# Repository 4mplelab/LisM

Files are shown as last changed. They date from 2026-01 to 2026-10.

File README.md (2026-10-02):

# LisM — 3Dモデル

モジュールを交換できる分割キーボード **LisM** のケース・キーキャップの3Dデータを公開しています。
このリポジトリでは3Dモデルを管理し、製品紹介やビルドガイドはWebサイトで案内しています。

## ドキュメント

- [LisM 製品紹介](https://4mplelab.github.io/LisM/)
- [ビルドガイド](https://4mplelab.github.io/LisM/build_guides/)

## 3Dデータ

データ形式は **STEP** です。

| 種類 | 保存先 |
| --- | --- |
| 本体ケース | [3d-data/case](3d-data/case/) |
| モジュールケース | [3d-data/case/modules](3d-data/case/modules/) |
| トラックボールユニット | [3d-data/case/units](3d-data/case/units/) |
| 旧型ケース | [3d-data/case/old_type](3d-data/case/old_type/) |
| キーキャップ | [3d-data/keycaps](3d-data/keycaps/) |

印刷前に、[ケースの印刷条件・オブジェクト構成](3d-data/case/README.md)や[キーキャップの説明](3d-data/keycaps/README.md)をご確認ください。
本体ケースのファイル名にある `v1.x.x` は、対応するPCBのバージョンを示します。

## ライセンス

データごとにライセンスが異なります。

- ケース： [CC BY-NC-SA 4.0](3d-data/case/LICENSE)
- キーキャップ： [CC BY 4.0](3d-data/keycaps/LICENSE)
- リポジトリルートのライセンス： [MIT](LICENSE)

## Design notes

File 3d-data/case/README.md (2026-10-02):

# ケースデータ



## 推奨印刷条件

各データは以下の条件で最適化されています。  
環境によっては正常に印刷できない可能性があります。

- 本体  
   `Bambu Lab P1S`, `0.4mmノズル`, `Standard品質`  

- その他 (モジュール・トラックボールケース)  
   `Bambu Lab A1 Mini`, `0.2mmノズル`, `Standard品質`

### ボトムケースの印刷方向

**ボトムケースは、底面がビルドプレートに対して垂直になるように立てて印刷してください。**
寝かせて印刷すると、はめ込み時に穴が潰れるため、底面をビルドプレートに置く向きでは印刷しないでください。

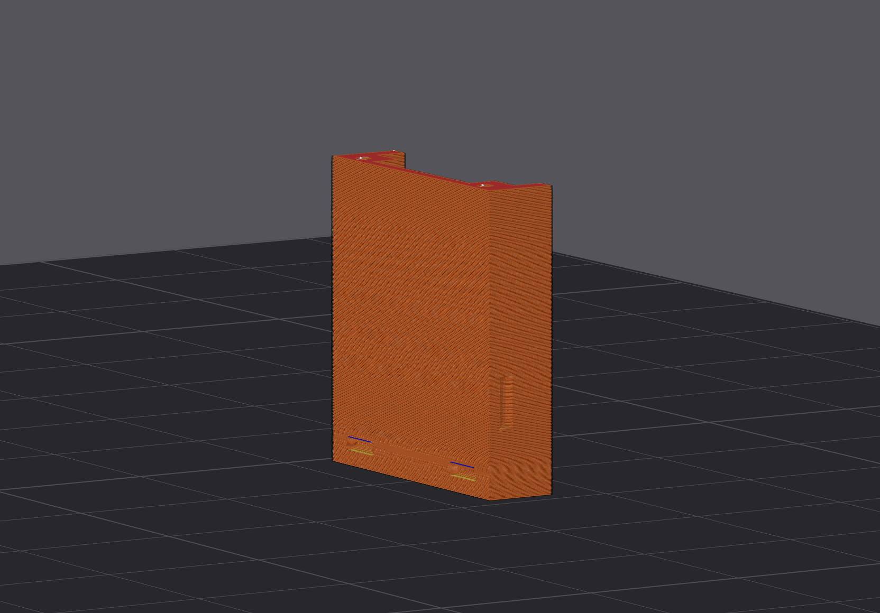
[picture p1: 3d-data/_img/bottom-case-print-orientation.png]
ボトムケースを立てて配置した印刷例


## STEPファイルのオブジェクト構成について

一部のSTEPファイルには、複数のデザインバリエーションが重なった状態で格納されています。(例: 本体ケースの、フラットデザイン・フローティングデザイン・リブ)  
任意の組み合わせ(例: フラットのみ、フローティング+リブ など)で印刷できるよう、CAD上でオブジェクトの表示/非表示を切り替えてご利用ください。

⚠️ 一部のオブジェクトが他のオブジェクトの陰に隠れて見えない場合があります。  
印刷前に、STEPファイル内のオブジェクト構成を必ずご確認ください。

## ファイル名のバージョンについて

`v1.x.x`の表記は、ケースのバージョンではなく**PCBのバージョン**を示しています。  
バージョンがご不明な場合は、PCB基板に印字されていますのでご確認ください。

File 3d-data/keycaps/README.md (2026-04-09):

# キーキャップデータ



## LAK 17mmピッチ用

<a href="../_img/lak17.png">
  
</a>

<a href="../_img/lak17_h.png">
  
</a>

**サイズ:** W 16.2mm × D 16.2mm × H 約6mm

### 確認済みキースイッチ

- Kailh Deep Sea Silent Mini
- Lofree Hades / Void
- Kailh Black Cloud
- Kailh Purple Iris
  
### 印刷

#### 確認済み環境

| 項目 | 値 |
|---|----|
| プリンター | Bambu Lab A1 Mini |
| ノズル | 0.2mm |
| 品質 | Standard |

#### スライス例   
<a href="../_img/lak17_slice.png">
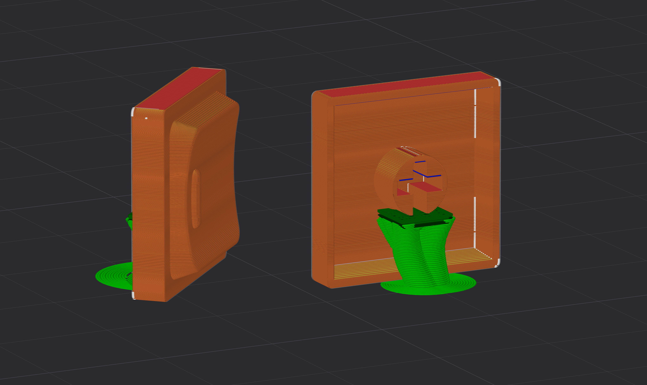
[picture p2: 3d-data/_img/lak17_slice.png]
  
</a>

---

### 注記
このキーキャップは、LAKプロファイルにインスパイアされています。  
形状は異なる寸法で独自に再設計したものであり、Chosfoxのオリジナル設計ファイルは一切使用していません。

> ⚠️ 第三者の知的財産権に関する保証はありません。  
> 商用利用前に、各自で知的財産権の状況を確認してください。

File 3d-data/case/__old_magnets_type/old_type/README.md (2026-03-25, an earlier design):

古いタイプのケースデータです。  
使用されている方もいると思うので互換性のために残しています。

現行はトラボセンサーをトラボケースに引っ掛ける使用ですが、それ以前のデータです。

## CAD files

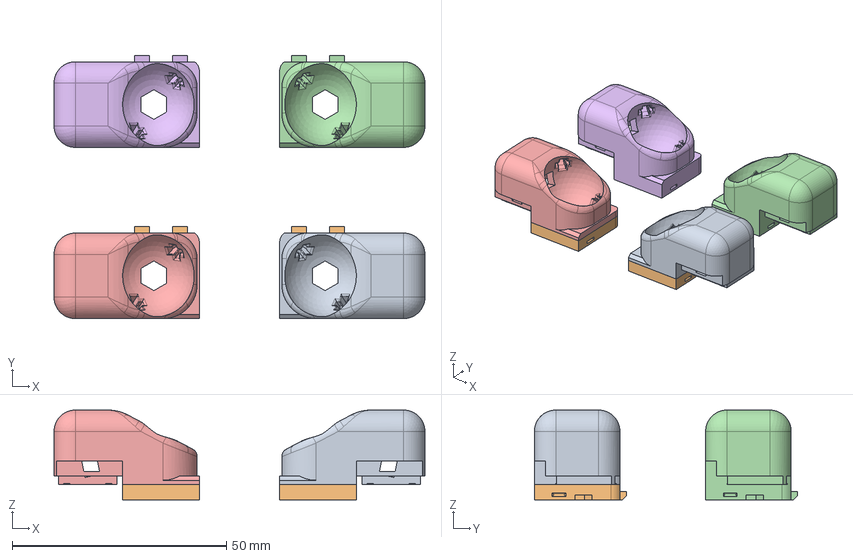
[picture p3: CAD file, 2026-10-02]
3d-data/case/units/TrackBall19mm.step
86.7 x 61.5 x 21.0 mm
19mmCase_Right_Cut
19mmCase_Right
19mmCase_Left_Cut
19mmCase_Left

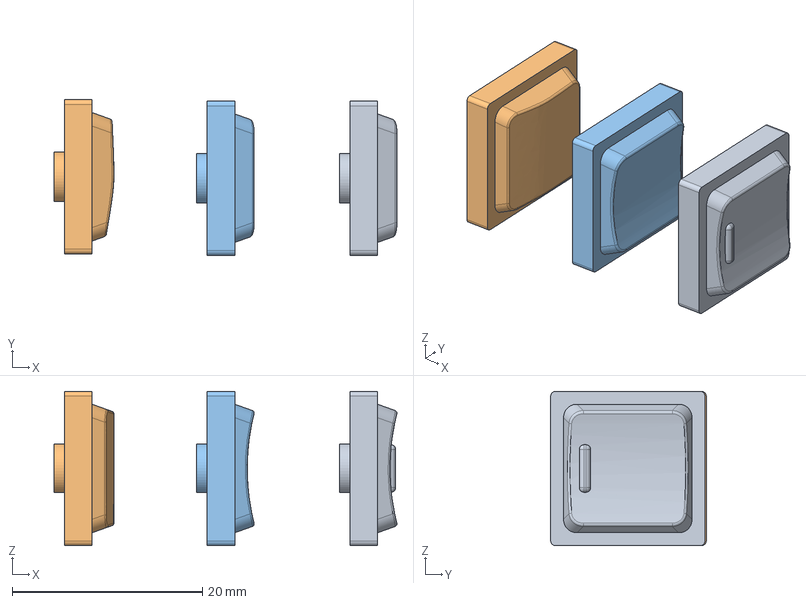
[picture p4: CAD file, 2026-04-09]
3d-data/keycaps/LAK_17mm.step
36.0 x 16.3 x 16.2 mm
Homing
Convex
Normal

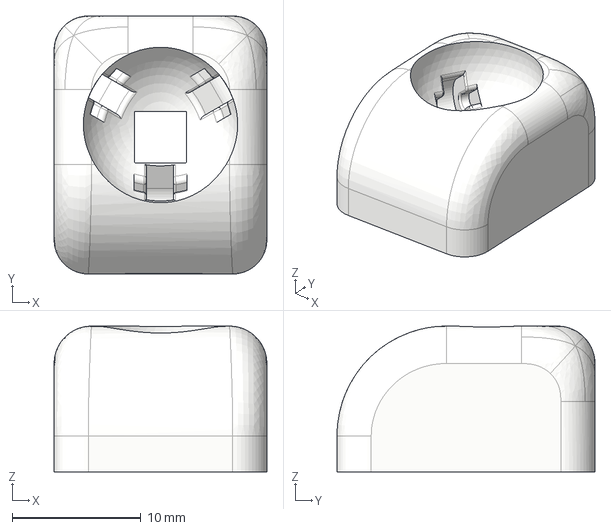
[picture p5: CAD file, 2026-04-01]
3d-data/case/units/TrackBall12mm.step
16.5 x 20.0 x 11.3 mm

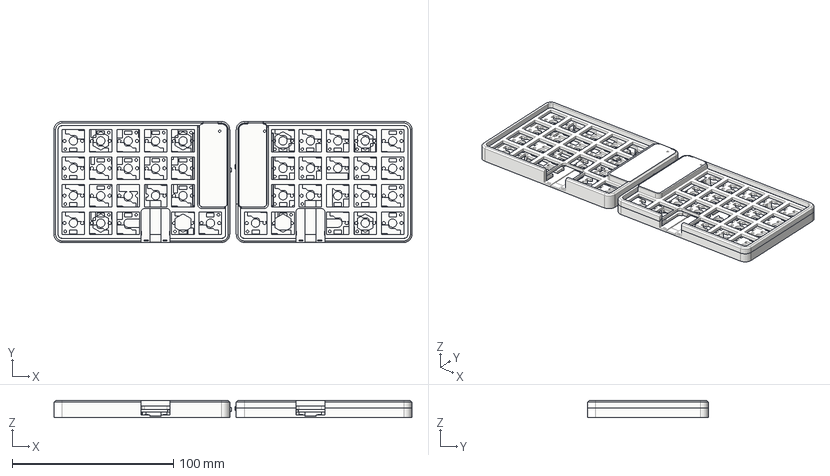
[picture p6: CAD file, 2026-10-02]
3d-data/case/LisM_v1.2.0.step
222.0 x 75.0 x 10.7 mm
Left_MagnetSpaceFiller
Left_BatterySpaceFiller
Left_PowerSwitch
Left_SwitchPlate
Left_MCUCover
Right_BatterySpaceFiller
Right_MagnetSpaceFiller
Right_SwitchPlate
Right_PowerSwitch
Right_MCUCover

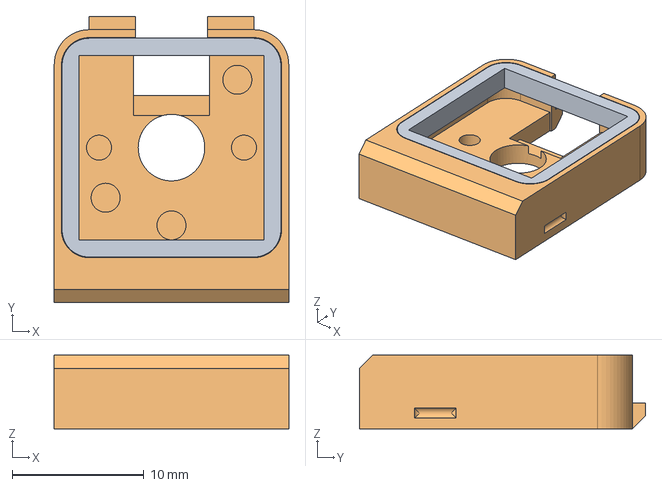
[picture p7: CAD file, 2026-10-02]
3d-data/case/modules/KeySwitch.step
17.8 x 21.7 x 5.60 mm
SwitchPlate
Case

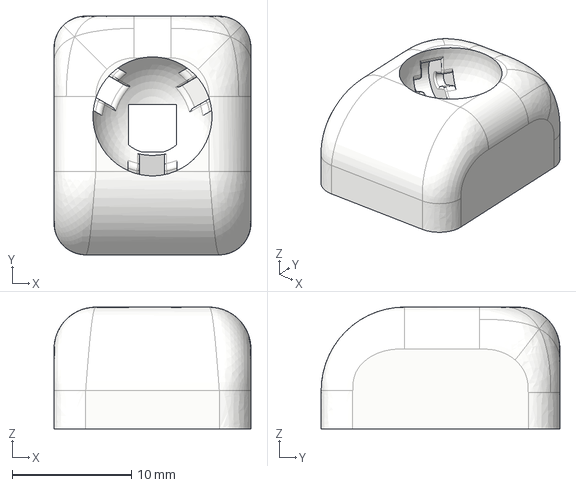
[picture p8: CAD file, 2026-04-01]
3d-data/case/units/TrackBall10mm.step
16.5 x 20.0 x 10.2 mm

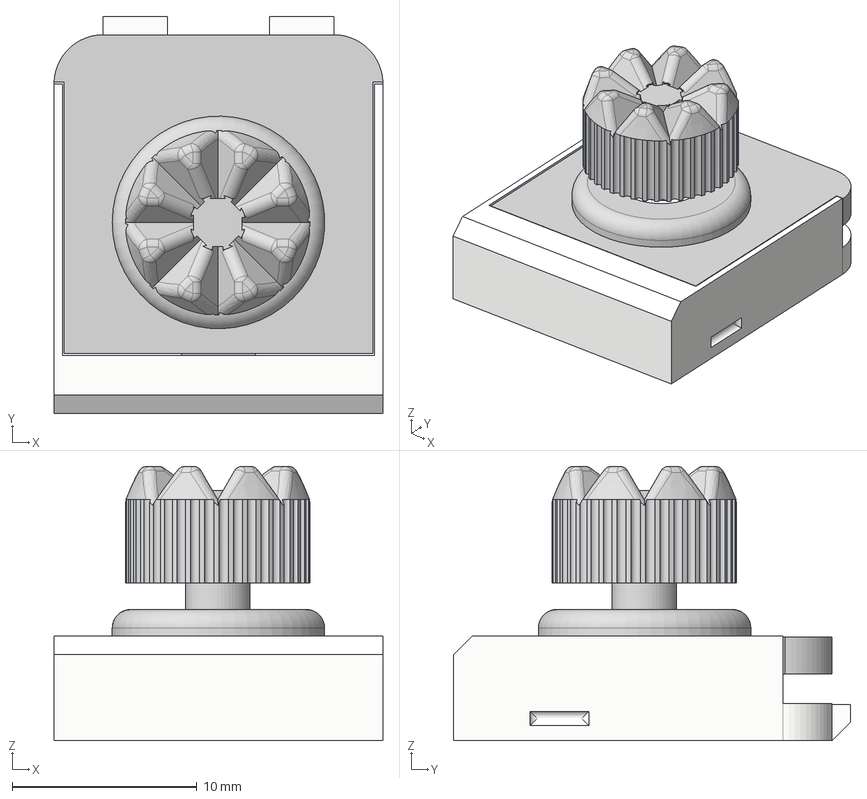
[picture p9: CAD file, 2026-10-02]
3d-data/case/modules/4wayStick.step
17.8 x 21.5 x 14.8 mm
BottomPart
TopPart
Stick_Cap
Stick_Crown

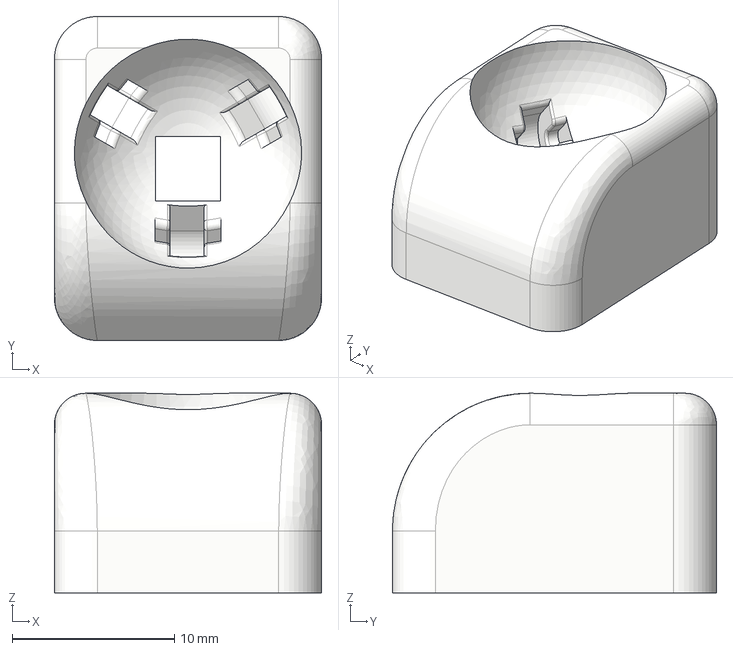
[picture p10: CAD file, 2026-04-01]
3d-data/case/units/TrackBall14mm.step
16.5 x 20.0 x 12.3 mm

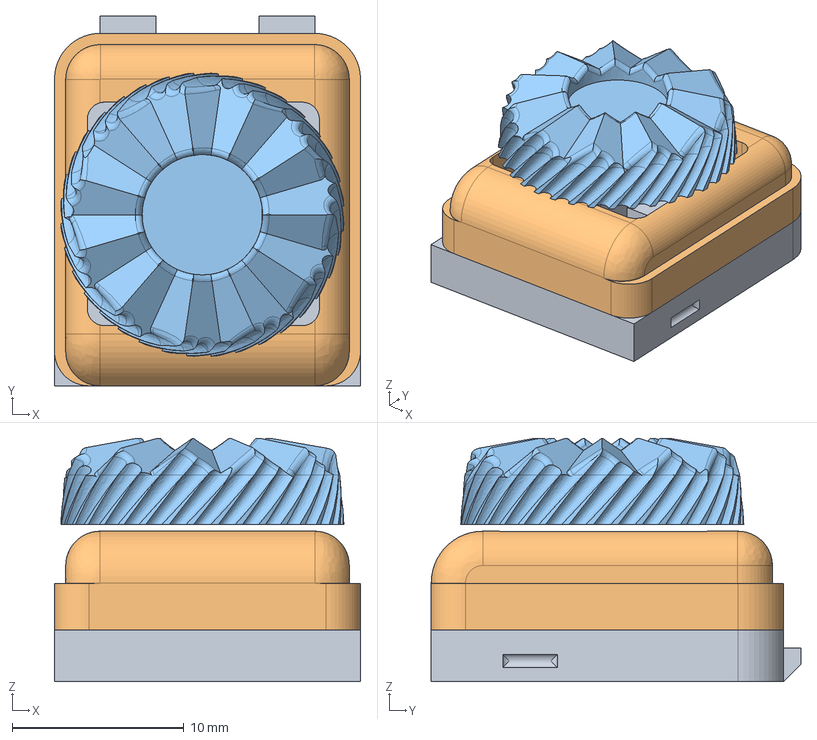
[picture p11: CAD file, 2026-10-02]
3d-data/case/modules/VerticalRotaryEncoder.step
17.8 x 21.5 x 14.2 mm
BottomPart
TopPart
Knob

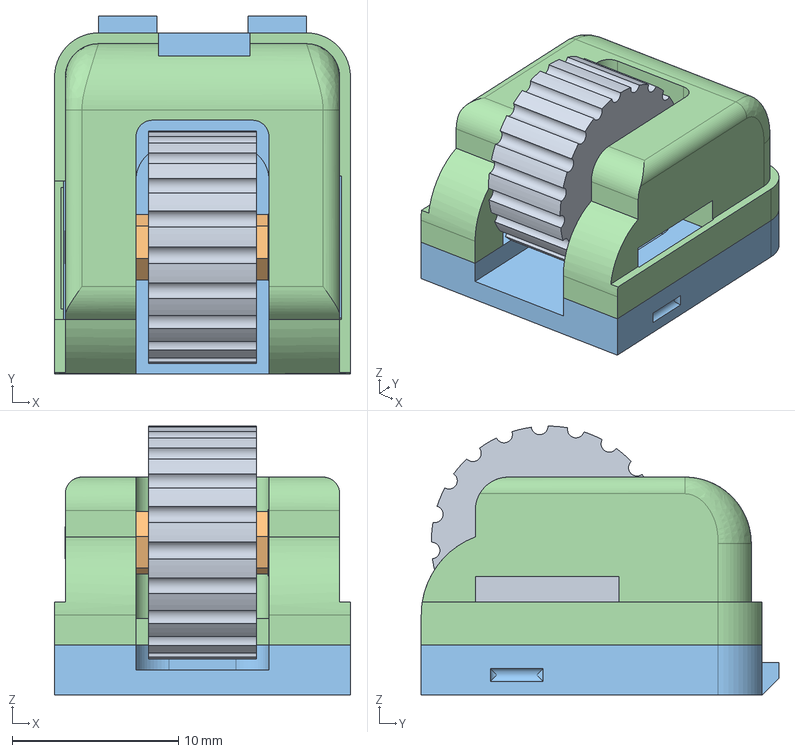
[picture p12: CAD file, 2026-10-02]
3d-data/case/modules/HorizontalRotaryEncoder.step
17.8 x 21.5 x 16.2 mm
Wheel
Stem
BottomPart
TopPart

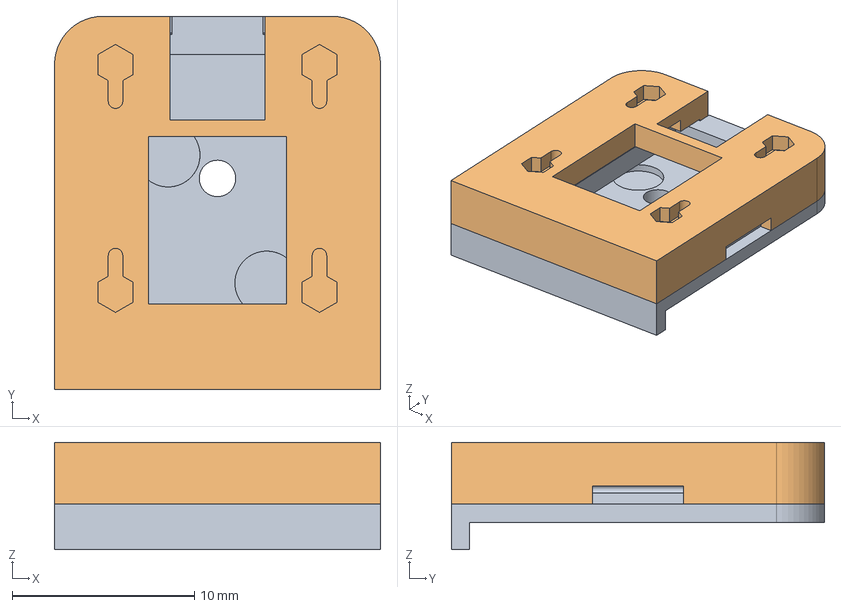
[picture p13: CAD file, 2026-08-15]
3d-data/case/modules/TrackBallSensor_v2.0.step
17.9 x 20.5 x 5.90 mm
BottomPart
TopPart

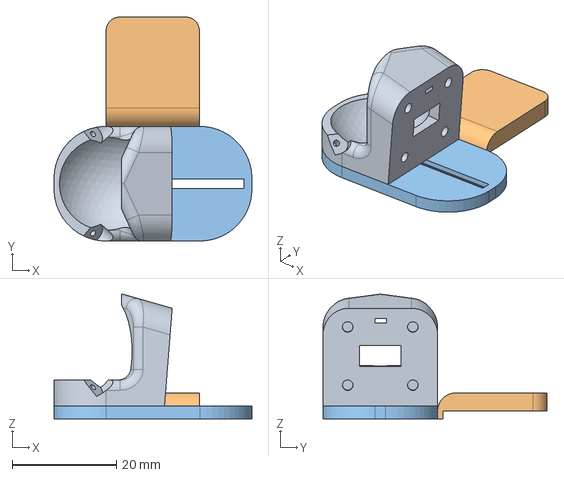
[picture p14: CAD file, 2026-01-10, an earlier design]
3d-data/case/__old_magnets_type/old_type/TrackBall20mm.step
38.0 x 43.0 x 24.0 mm
20mmCase
Bracket

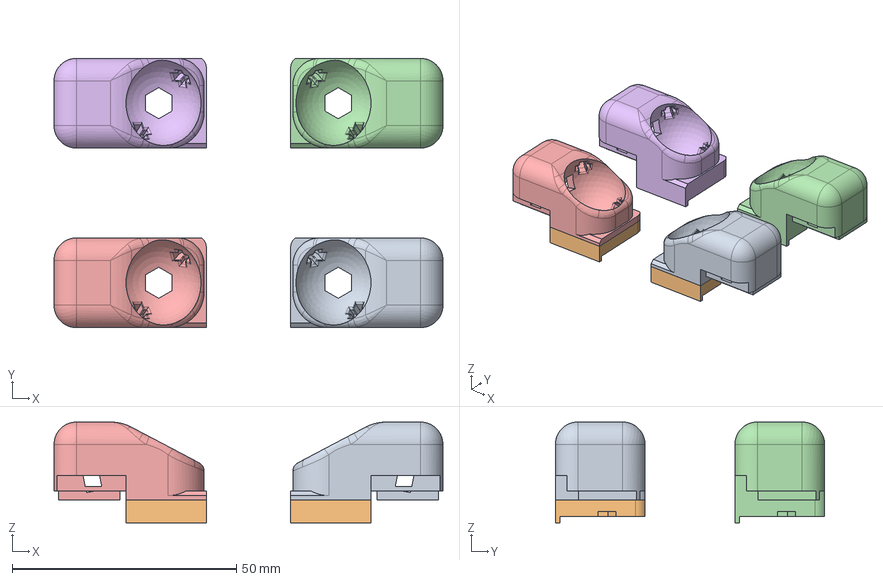
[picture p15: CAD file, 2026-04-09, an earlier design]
3d-data/case/__old_magnets_type/units/TrackBall19mm.step
86.7 x 60.0 x 22.5 mm
19mmCase_Right_Cut
19mmCase_Right
19mmCase_Left_Cut
19mmCase_Left

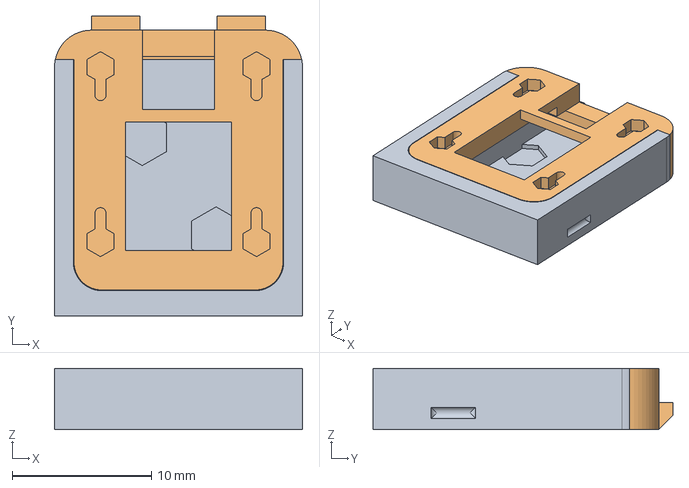
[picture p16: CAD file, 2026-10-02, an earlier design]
3d-data/case/modules/TrackBallSensor_v2.step
17.8 x 21.5 x 4.40 mm
BottomPart
TopPart

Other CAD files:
3d-data/case/__old_magnets_type/LisM_v1.2.0.step
3d-data/case/LisM_v1.1.0.step
3d-data/case/__old_magnets_type/LisM_v1.0.0.step
3d-data/case/LisM_v1.0.0.step
3d-data/case/__old_magnets_type/LisM_v1.1.0.step
3d-data/case/__old_magnets_type/modules/4wayStick.step
3d-data/case/__old_magnets_type/modules/HorizontalRotaryEncoder.step
3d-data/case/__old_magnets_type/modules/KeySwitch.step
3d-data/case/__old_magnets_type/modules/TrackBallSensor.step
3d-data/case/__old_magnets_type/modules/VerticalRotaryEncoder.step
3d-data/case/__old_magnets_type/old_type/TrackBall10mm.step
3d-data/case/__old_magnets_type/old_type/TrackBall12mm.step
3d-data/case/__old_magnets_type/old_type/TrackBall14mm.step
3d-data/case/__old_magnets_type/old_type/TrackBallSensor.step
3d-data/case/__old_magnets_type/old_type/TrackBallSensor_SnapFit.step
3d-data/case/modules/TrackBallSensor.step
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

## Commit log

2025-10-24 Add 3D models.
    [HorizontalRotaryEncoder.step, KeySwitch.step, LisM.step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]
2025-10-28 update 3D models.
    Expanded battery space
    [LisM.step, TrackBallSensor.step]
2025-10-30 3Dモデル 軽微な修正
    [KeySwitch.step, TrackBall20mm.step, TrackBallSensor.step]
2025-11-23 本体ケースアップデート・リネーム
    [LisM.step, LisM_v1.0.0.step]
2025-11-23 本体ケース PCB v1.1.0対応
    [LisM_v1.1.0.step]
2025-11-23 バージョンについての説明追記
2025-12-09 トラボセンサーケースへスナップフィット＋マグネット版を追加
    [TrackBallSensor_SnapFit.step]
2025-12-09 フローティングデザイン追加/フラットデザインの改善
    [LisM_v1.0.0.step, LisM_v1.1.0.step]
2025-12-23 3Dデータ 軽微な修正
    [HorizontalRotaryEncoder.step, TrackBall10mm.step, TrackBall12mm.step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]
2025-12-26 10mmケースの適正距離修正
    [TrackBall10mm.step]
2026-01-10 14mmケースのセンサー距離不足修正
    [TrackBall14mm.step]
2026-01-10 軽微な修正
    [TrackBall10mm.step, TrackBall12mm.step, TrackBall20mm.step]
2026-02-05 一部モジュールの高さがスイッチプレートと揃うように修正
    [HorizontalRotaryEncoder.step, KeySwitch.step, VerticalRotaryEncoder.step]
2026-02-17 キースイッチケースの穴を少し広げる
    盛り盛りハンダ付け対応
    [KeySwitch.step]
2026-03-25 19mmトラボケース追加
    [TrackBall19mm.step]
2026-03-25 ケース刷新
    [HorizontalRotaryEncoder.step, KeySwitch.step, TrackBall10mm.step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]
2026-03-27 本体(pcb: ver1.2.0)ケース修正
    LIR1655用の凹み拡大
2026-04-01 10-14mmトラボケース センサー部拡張
    個体差できつすぎる場合ありのため
    [TrackBall10mm.step, TrackBall12mm.step, TrackBall14mm.step]
2026-04-09 マグネット部を少し狭く
    [VerticalRotaryEncoder.step]
2026-04-09 レンズやPCB部のマージン拡張
    [TrackBallSensor.step, TrackBallSensor_v2.0.step]
2026-04-09 beekeebさんのトラックボール対応
    [TrackBall19mm.step]
2026-04-09 LAKっぽい17mmピッチ用キーキャップ追加
    [LAK_17mm.step]
2026-04-09 注記追加
2026-06-27 本体ケースへ左右連結用マグネット取り付け穴追加
    [HorizontalRotaryEncoder.step, KeySwitch.step, LisM_v1.2.0.step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]
2026-07-02 垂直エンコーダー トップケース変更（前面を印刷しやすい形状へ）
    [VerticalRotaryEncoder.step]
2026-07-11 本体ケース 全バージョン背面マグネット対応
    [LisM_v1.0.0.step, LisM_v1.1.0.step]
2026-07-23 4wayスティックモジュールケース追加
    [4wayStick.step]
2026-08-05 4wayスティックのスティック部修正
    [4wayStick.step]
2026-08-05 垂直エンコーダーノブ形状変更
    [VerticalRotaryEncoder.step]
2026-08-15 トラボセンサーケース コンデンサ干渉を修正
    [TrackBallSensor_v2.0.step]
2026-09-03 マイコンカバーの穴をφ1.2mmからφ1.5mmへ
    [LisM_v1.2.0.step]
2026-09-04 ファイル破損のため修正（マイコンカバーの穴をφ1.2mmからφ1.5mmへ）
    [LisM_v1.2.0.step]
2026-10-02 Update snap-fit case models and documentation
    [4wayStick.step, HorizontalRotaryEncoder.step, KeySwitch.step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]
